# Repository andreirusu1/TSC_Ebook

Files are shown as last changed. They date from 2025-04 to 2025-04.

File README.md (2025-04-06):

# TSC_Ebook
Descriere Proiect
OpenBook este un proiect open source care isi propune sa creeze un e-book reader accesibil si usor de produs. Dispozitivul este conceput pentru a afisa carti digitale, oferind o experienta de lectura similara cu cea a unei carti tiparite, dar cu avantajele tehnologiei moderne. Proiectul meu se bazeaza pe o proiectare simpla si eficienta, iar in aceasta etapa s-au dezvoltat schema electronica, PCB-ul si plasarea componentelor pe placa.

Pentru a transforma aceasta viziune in realitate, am parcurs urmatoarele etape:

1)Engineering Validation (EVT): Am proiectat schema electronica si am creat PCB-ul, asigurandu-ne ca fiecare conexiune este optimizata pentru performanta si fiabilitate.

2)Modelare 3D: Am verificat plasarea componentelor pe placa intr-un mediu 3D, garantand ca designul se integreaza perfect in cadrul final al dispozitivului.

3)Partea de display, baterie si modelele 3D complete ale dispozitivului nu au fost dezvoltate inca. Acest repository se concentreaza pe proiectarea schematica, realizarea PCB-ului si plasarea componentelor pe placa in mediul 3D.

Diagrama Bloc

Mai jos se prezinta o diagrama bloc schematica a principalelor componente si a interconexiunilor acestora:
diagrama

Bill Of Materials (BOM)
Nr.	Componenta	Datasheet URL	Link site pt procurare

1	ESP32-C6-WROOM-1-N8	[Datasheet](https://www.espressif.com/sites/default/files/documentation/esp32-c6-wroom-1_wroom-1u_datasheet_en.pdf)	[link](https://www.digikey.com/en/products/detail/espressif-systems/ESP32-C6-WROOM-1-N8/17728866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)

2	Micro-SD	[Datasheet](https://www.attend.com.tw/data/download/file/112A-TAAR-R03_Spec.pdf)	[link](https://www.digikey.com/en/products/detail/attend-technology/112A-TAAR-R03/17633923)

3	Inductor (68µH)	[Datasheet](https://www.we-online.com/components/products/datasheet/784373170680.pdf)	[link](https://ro.mouser.com/ProductDetail/Wurth-Elektronik/784373170680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)

4	LED	[Datasheet](https://www.bridgelux.com/sites/default/files/resource_media/DS51_Rev%20F%20Bridgelux%20SMD%203030%20Data%20sheet.pdf)	[link](https://www.digikey.com/en/products/detail/bridgelux/BXEM-27E0000-0-000/6618599)

5	Buttons	[Datasheet](https://configured-product-images.s3.amazonaws.com/Datasheets/TL3315.pdf)	[link](https://www.digikey.com/en/products/detail/e-switch/TL3315NF250Q/1870396)

6	Capacitor 	[Datasheet](https://eu.mouser.com/datasheet/2/40/cx5r_KGM-3223198.pdf)	[link](https://ro.mouser.com/ProductDetail/KYOCERA-AVX/0402YD104MAT2A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)

7	Rezistori	[Datasheet](https://www.yageo.com/upload/media/product/products/datasheet/rchip/PYu-RC_Group_51_RoHS_L_12.pdf)	[link](https://www.digikey.com/en/products/detail/yageo/RC0402JR-07100KL/726416)

8	Diode (Schottky Rectifier)	[Datasheet](https://datasheets.kyocera-avx.com/schottky.pdf)	[link](https://www.digikey.com/en/products/detail/kyocera-avx/sd0805s020s1r0/3749517)

9	Connector USB (Type-C)	[Datasheet](https://gct.co/files/drawings/usb4110.pdf)	[Mouser](https://ro.mouser.com/ProductDetail/GCT/USB4110-GF-A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)

10	Test Pad 	[DataSheet](https://cdn-shop.adafruit.com/product-files/3825/3825_diagram.PDF) [link](https://componentsearchengine.com/prices/3825?manufacturer=Adafruit)

 Aceasta lista este orientativa. Componentele si specificatiile pot fi ajustate pe parcursul dezvoltarii.

Functionalitatea Hardware
Proiectul se bazeaza pe microcontroller-ul ESP32-C6, iar designul hardware a fost gandit pentru a optimiza functionalitatea si integrarea componentelor. Principalele aspecte includ:

Alimentare: Dispozitivul este alimentat printr-un regulator de tensiune care transforma 5V in 3.3V, necesar pentru functionarea corecta a ESP32-C6.

Conectivitate: ESP32-C6 pune la dispozitie mai multe interfete de comunicatie (UART, SPI, I2C), esentiale pentru conectarea senzorilor si a altor periferice.

Plasare Componentelor: Schematicul si PCB-ul au fost proiectate pentru a asigura o dispunere eficienta a componentelor, reducand interferentele electromagnetice si facilitand asamblarea manuala sau automatizata.

Verificare 3D: Modelul 3D realizat in Fusion360 (exportat ca .step) a fost folosit pentru a verifica plasarea corecta a componentelor pe placa.

Configurarea Pinilor ESP32-C6
Mai jos sunt detaliate functiile pinilor utilizati in proiect:

Pin	    Functie	          Descriere
GPIO1	  TX	            Transmiterea datelor catre periferice

GPIO3	  RX	            Receptionarea datelor de la periferice

GPIO12	I2C             SDA	Linie de date pentru comunicatia I2C

GPIO13	I2C             SCL	Linie de ceas pentru comunicatia I2C

GPIO14	Buton/Resetare	Functie de resetare a dispozitivului

Configuratia pinilor poate fi ajustata.

Planuri de Dezvoltare: Etapele urmatoare includ integrarea componentelor pentru display, alimentare prin baterie si dezvoltarea completa a modelului 3D al dispozitivului pentru validarea finala.

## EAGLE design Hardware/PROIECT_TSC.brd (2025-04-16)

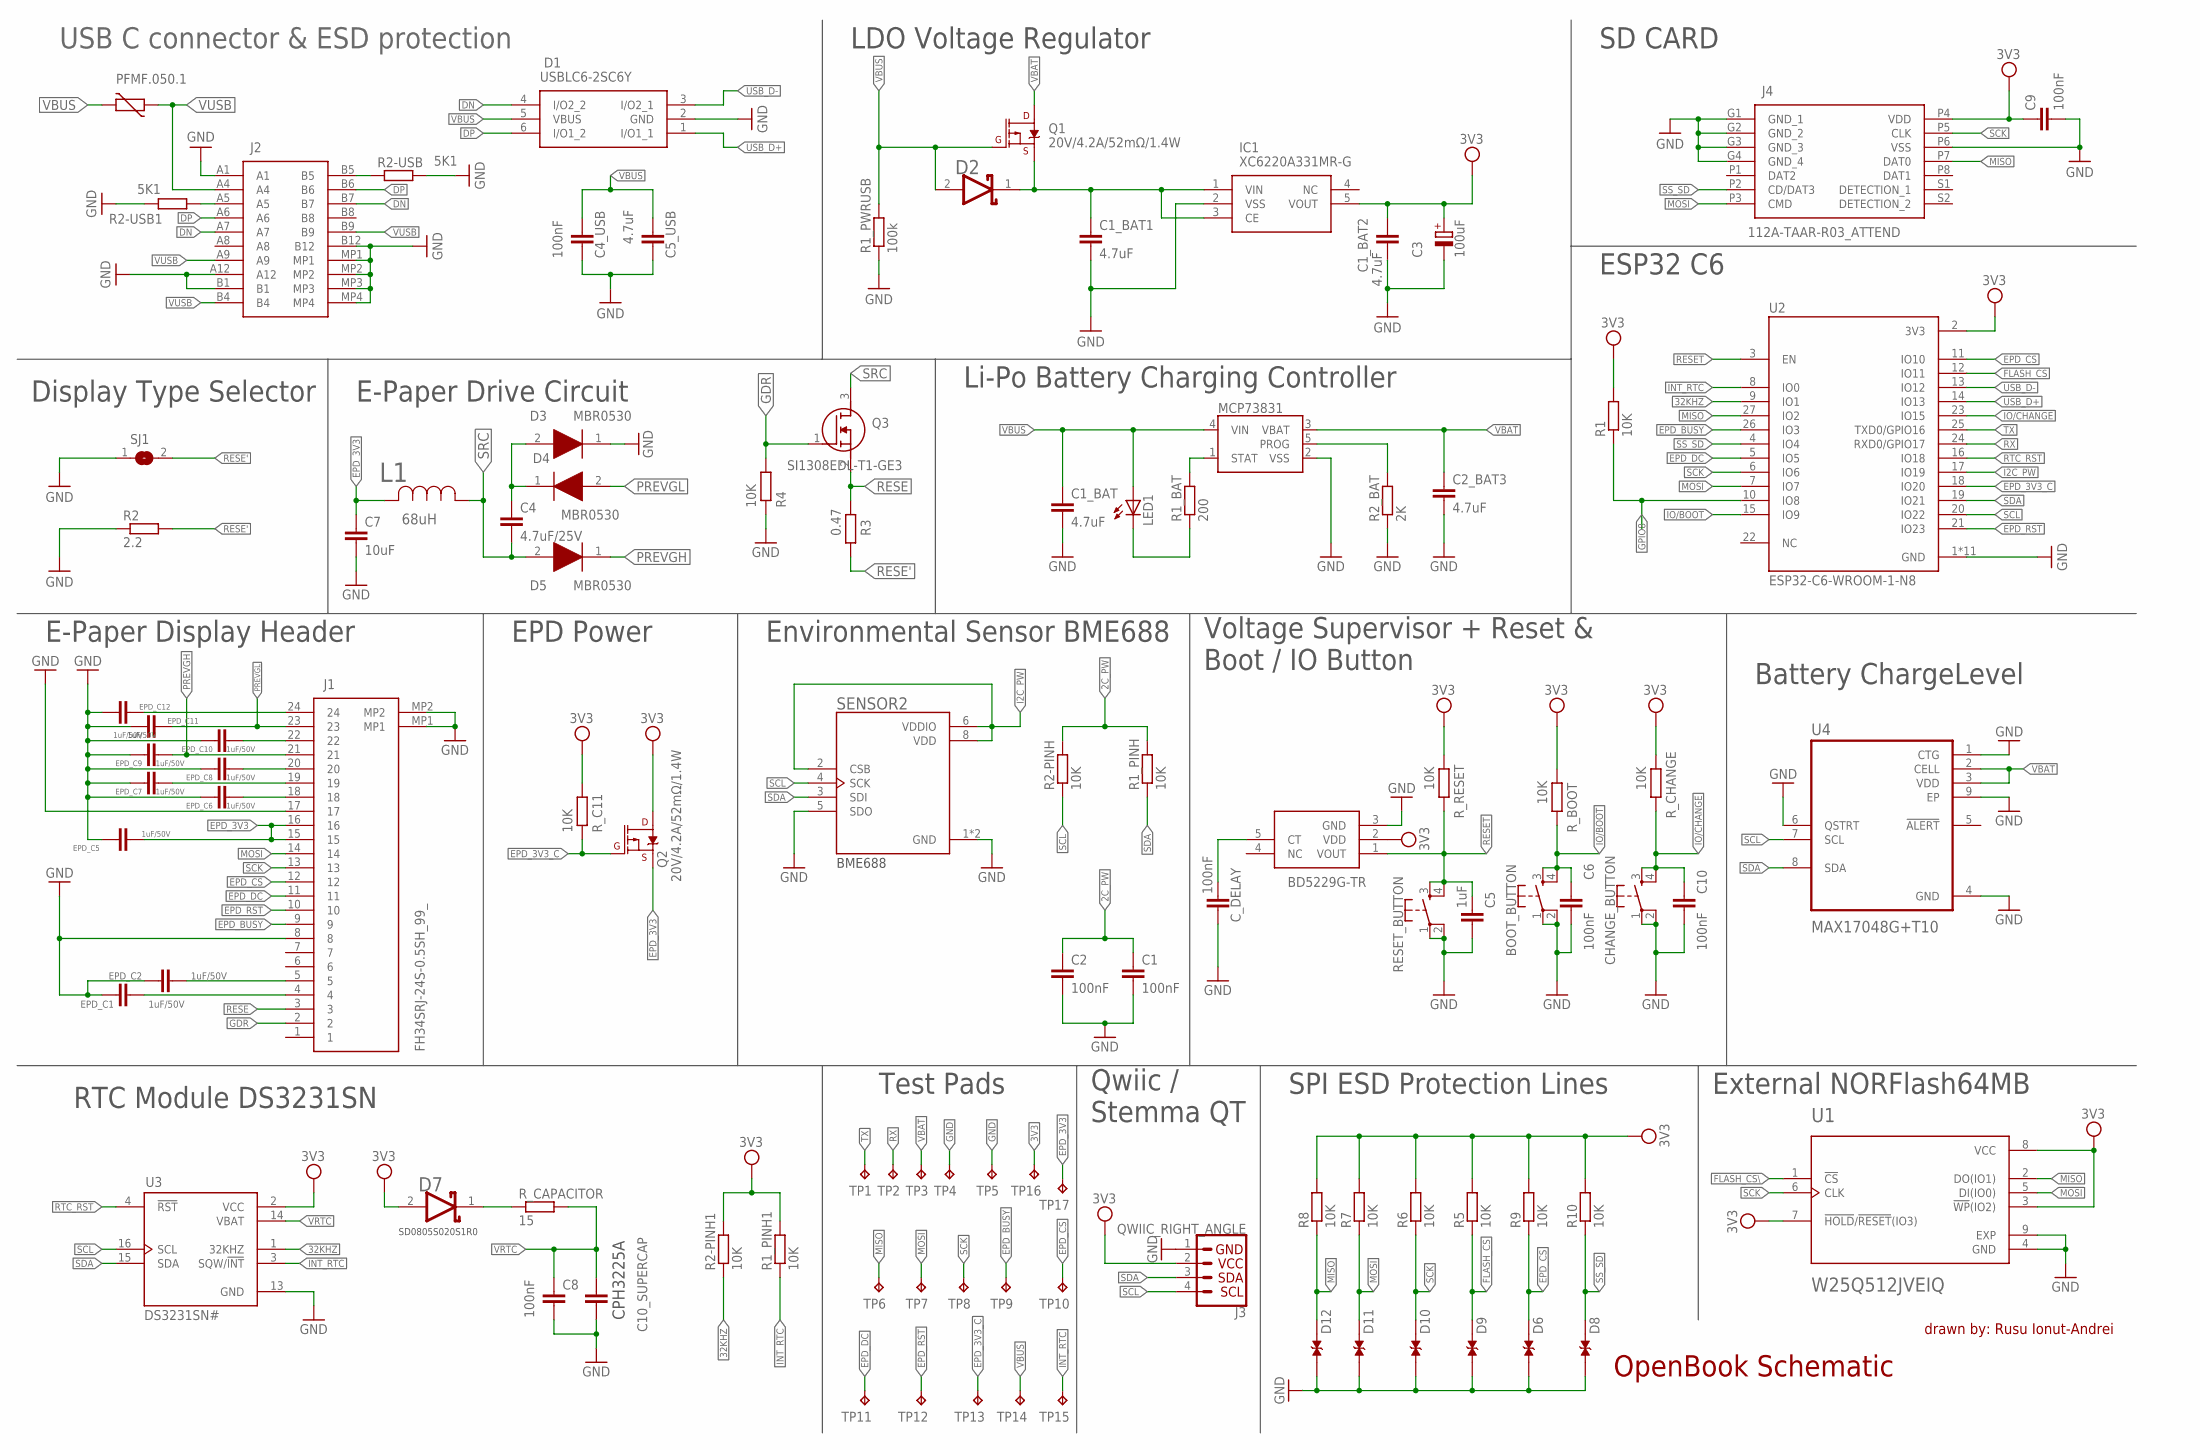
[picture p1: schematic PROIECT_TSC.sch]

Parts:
BOOT_BUTTON: BUTTON_CUSYOMV1; MYBUTTON
C1, C2, C6, C8, C9, C10: 100nF; ESP32_WROVER_EAGLE-LTSPICE_C0402
C1_BAT, C1_BAT1, C2_BAT3: 4.7uF; ESP32_WROVER_EAGLE-LTSPICE_C0402
C1_BAT2, C5_USB: 4.7uF; EAGLE-LTSPICE_C0402
C3: 100uF; RCL_CT3528
C4: 4.7uF/25V; ESP32_WROVER_EAGLE-LTSPICE_C0402
C4_USB: 100nF; EAGLE-LTSPICE_C0402
C5: 1uF; ESP32_WROVER_EAGLE-LTSPICE_C0402
C7: 10uF; EAGLE-LTSPICE_C0402
C10_SUPERCAP: ESP32_WROVER_EAGLE-LTSPICE_CC0402; ESP32_WROVER_EAGLE-LTSPICE_C0402
CHANGE_BUTTON: BUTTON_CUSYOMV1; MYBUTTON
C_DELAY: 100nF; ESP32_WROVER_EAGLE-LTSPICE_C0402
D1: USBLC6-2SC6Y; SOT95P280X145-6N
D2, D7: ESP32_WROVER_AVX---SD0805S020S1R0_AVX_SD0805S020S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; ESP32_WROVER_AVX---SD0805S020S1R0_AVX_SD0805S020S1R0_0
D3, D4, D5: MBR0530; SOD3716X135N
D6, D8, D9, D10, D11, D12: PGB1010603MR; DIOC1608X36N
EPD_C1, EPD_C2, EPD_C5, EPD_C6, EPD_C7, EPD_C8, EPD_C9, EPD_C10, EPD_C11, EPD_C12: 1uF/50V; ESP32_WROVER_EAGLE-LTSPICE_C0402
IC1: XC6220A331MR-G; SOT95P280X120-5N
IC2: BD5229G-TR; SOT95P280X125-5N
J1: FH34SRJ-24S-0.5SH_99_; FH34SRJ24S05SH99
J2: SAMACSYS_PARTS_USB4110-GF-A; SAMACSYS_PARTS_USB4110GFA
J3: QWIIC_RIGHT_ANGLE; JST04_1MM_RA
J4: 112A-TAAR-R03_ATTEND; 112ATAARR03ATTEND
L1: 68uH; IND_4828-WE-TPC_WRE
LED1: ADAFRUIT_LEDCHIP-LED0603; ADAFRUIT_CHIP-LED0603
MCP73831: ESP32_WROVER_SPARKFUN-IC-POWER_MCP73831; ESP32_WROVER_SPARKFUN-IC-POWER_SOT23-5
PFMF.050.1: ESP32C6_VARISTORCN1812; ESP32C6_VARISTOR_CT/CN1812
Q1, Q2: 20V/4.2A/52mΩ/1.4W; ESP32_WROVER_SPARKFUN-DISCRETESEMI_SOT23-3
Q3: SI1308EDL-T1-GE3; SOT65P210X110-3N
R1, R1_PINH, R1_PINH1, R2-PINH, R2-PINH1, R4, R5, R6, R7, R8, R9, R10: 10K; ESP32_WROVER_EAGLE-LTSPICE_R0402
R1_BAT: 200; ESP32_WROVER_EAGLE-LTSPICE_R0402
R1_PWRUSB: 100k; ESP32_WROVER_EAGLE-LTSPICE_R0402
R2: 2.2; ESP32_WROVER_EAGLE-LTSPICE_R0402
R2-USB, R2-USB1: 5K1; ESP32_WROVER_EAGLE-LTSPICE_R0402
R2_BAT: 2K; ESP32_WROVER_EAGLE-LTSPICE_R0402
R3: 0.47; ESP32_WROVER_EAGLE-LTSPICE_R0402
RESET_BUTTON: BUTTON_CUSYOMV1; MYBUTTON
R_BOOT: 10K; ESP32_WROVER_EAGLE-LTSPICE_R0402
R_C11: 10K; ESP32_WROVER_EAGLE-LTSPICE_R0402
R_CAPACITOR: 15; ESP32_WROVER_EAGLE-LTSPICE_R0402
R_CHANGE: 10K; ESP32_WROVER_EAGLE-LTSPICE_R0402
R_RESET: 10K; ESP32_WROVER_EAGLE-LTSPICE_R0402
SENSOR2: ESP32_WROVER_BME680_BME680; ESP32_WROVER_BME680_PSON80P300X300X100-8N
SJ1: SJ
TP1, TP2, TP3, TP4, TP5, TP6, TP7, TP8, TP9, TP10, TP11, TP12, TP13, TP14, TP15, TP16, TP17: TPTP20R; TP20R
U1: W25Q512JVEIQ; SON127P600X800X80-9N
U2: ESP32-C6-WROOM-1-N8; XCVR_ESP32-C6-WROOM-1-N8
U3: DS3231SN#; SOIC127P1032X265-16N
U4: MAX17048G+T10; SON50P200X200X80-9N

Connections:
2C_PW: C1.1, C2.1, R1_PINH.2, R2-PINH.2
3V3: C1_BAT2.1, C3.+, C9.1, D7.2 (ANODE), IC1.5 (VOUT), IC2.2 (VDD), J3.2, J4.P4 (VDD), Q2.3 (D), R1.2, R1_PINH1.2, R2-PINH1.2, R5.2, R6.2, R7.2, R8.2, R9.2, R10.2, R_BOOT.2, R_C11.2, R_CHANGE.2, R_RESET.2, TP16.TP, U1.3 (!WP!(IO2)), U1.7 (!HOLD!/!RESET!(IO3)), U1.8 (VCC), U2.2 (3V3), U3.2 (VCC)
32KHZ: R2-PINH1.1, U2.9 (IO1), U3.1 (32KHZ)
DN: D1.4 (I/O2_2), J2.A7, J2.B7
DP: D1.6 (I/O1_2), J2.A6, J2.B6
EPD_3V3: C7.1, EPD_C5.2, J1.15, J1.16, L1.2, Q2.2 (S), TP17.TP
EPD_3V3_C: Q2.1 (G), R_C11.1, TP13.TP, U2.18 (IO20)
EPD_BUSY: J1.9, TP9.TP, U2.26 (IO3)
EPD_CS: D6.2, J1.12, R9.1, TP10.TP, U2.11 (IO10)
EPD_DC: J1.11, TP11.TP, U2.5 (IO5)
EPD_RST: J1.10, TP12.TP, U2.21 (IO23)
FLASH_CS: D9.2, R5.1, U2.12 (IO11)
FLASH_CS\: U1.1 (!CS)
GDR: J1.2, Q3.1 (G), R4.2
GND: BOOT_BUTTON.1, BOOT_BUTTON.2, C1.2, C1_BAT.2, C1_BAT1.2, C1_BAT2.2, C2.2, C2_BAT3.2, C3.-, C4_USB.2, C5.2, C5_USB.2, C6.2, C7.2, C8.2, C9.2, C10.2, C10_SUPERCAP.2, CHANGE_BUTTON.1, CHANGE_BUTTON.2, C_DELAY.2, D1.2 (GND), D3.1 (K), D6.1, D8.1, D9.1, D10.1, D11.1, D12.1, EPD_C1.1, EPD_C2.1, EPD_C5.1, EPD_C6.1, EPD_C7.1, EPD_C8.1, EPD_C9.1, EPD_C10.1, EPD_C11.1, EPD_C12.1, IC1.2 (VSS), IC2.3 (GND), J1.8, J1.17, J1.MP1, J1.MP2, J2.A1, J2.A12, J2.B1, J2.B12, J2.MP1, J2.MP2, J2.MP3, J2.MP4, J3.1, J4.G1 (GND_1), J4.G2 (GND_2), J4.G3 (GND_3), J4.G4 (GND_4), J4.P6 (VSS), MCP73831.2 (VSS), R1_PWRUSB.1, R2.1, R2-USB.2, R2-USB1.1, R2_BAT.1, R4.1, RESET_BUTTON.1, RESET_BUTTON.2, SENSOR2.1 (GND), SENSOR2.5 (SDO), SENSOR2.7 (GND), SJ1.1, TP4.TP, TP5.TP, U1.4 (GND), U1.9 (EXP), U2.1 (GND), U2.28 (GND), U2.29_1 (GND), U2.29_2 (GND), U2.29_3 (GND), U2.29_4 (GND), U2.29_5 (GND), U2.29_6 (GND), U2.29_7 (GND), U2.29_8 (GND), U2.29_9 (GND), U3.13 (GND), U4.1 (CTG), U4.4 (GND), U4.6 (QSTRT), U4.9 (EP)
GPIO8: R1.1, U2.10 (IO8)
I2C_PW: SENSOR2.2 (CSB), SENSOR2.6 (VDDIO), SENSOR2.8 (VDD), U2.17 (IO19)
INT_RTC: R1_PINH1.1, TP15.TP, U2.8 (IO0), U3.3 (SQW/!INT)
IO/BOOT: BOOT_BUTTON.3, BOOT_BUTTON.4, C6.1, R_BOOT.1, U2.15 (IO9)
IO/CHANGE: C10.1, CHANGE_BUTTON.3, CHANGE_BUTTON.4, R_CHANGE.1, U2.23 (IO15)
MISO: D12.2, J4.P7 (DAT0), R8.1, TP6.TP, U1.2 (DO(IO1)), U2.27 (IO2)
MOSI: D11.2, J1.14, J4.P3 (CMD), R7.1, TP7.TP, U1.5 (DI(IO0)), U2.7 (IO7)
unnamed: C1_BAT1.1, D2.1 (CATHODE), IC1.1 (VIN), IC1.3 (CE), Q1.2 (S)
unnamed: J2.A5, R2-USB1.2
unnamed: C4.1, D3.2 (A), D4.1 (K)
unnamed: J2.B5, R2-USB.1
unnamed: MCP73831.1 (STAT), R1_BAT.2
unnamed: MCP73831.5 (PROG), R2_BAT.2
unnamed: LED1.C, R1_BAT.1
unnamed: EPD_C12.2, J1.24
unnamed: EPD_C2.2, J1.5
unnamed: EPD_C1.2, J1.4
unnamed: EPD_C6.2, J1.18
unnamed: EPD_C10.2, J1.22
unnamed: EPD_C8.2, J1.20
unnamed: D7.1 (CATHODE), R_CAPACITOR.1
unnamed: EPD_C7.2, J1.19
unnamed: C_DELAY.1, IC2.5 (CT)
PREVGH: D5.1 (K), EPD_C9.2, J1.21
PREVGL: D4.2 (A), EPD_C11.2, J1.23
RESE: J1.3, Q3.2 (S), R3.2
RESE': R2.2, R3.1, SJ1.2
RESET: C5.1, IC2.1 (VOUT), RESET_BUTTON.3, RESET_BUTTON.4, R_RESET.1, U2.3 (EN)
RTC_RST: U2.16 (IO18), U3.4 (!RST)
RX: TP2.TP, U2.24 (RXD0/GPIO17)
SCK: D10.2, J1.13, J4.P5 (CLK), R6.1, TP8.TP, U1.6 (CLK), U2.6 (IO6)
SCL: J3.4, R2-PINH.1, SENSOR2.4 (SCK), U2.20 (IO22), U3.16 (SCL), U4.7 (SCL)
SDA: J3.3, R1_PINH.1, SENSOR2.3 (SDI), U2.19 (IO21), U3.15 (SDA), U4.8 (SDA)
SRC: C4.2, D5.2 (A), L1.1, Q3.3 (D)
SS_SD: D8.2, J4.P2 (CD/DAT3), R10.1, U2.4 (IO4)
TX: TP1.TP, U2.25 (TXD0/GPIO16)
USB_D+: D1.1 (I/O1_1), U2.14 (IO13)
USB_D-: D1.3 (I/O2_1), U2.13 (IO12)
VBAT: C2_BAT3.1, MCP73831.3 (VBAT), Q1.3 (D), TP3.TP, U4.2 (CELL), U4.3 (VDD)
VBUS: C1_BAT.1, C4_USB.1, C5_USB.1, D1.5 (VBUS), D2.2 (ANODE), LED1.A, MCP73831.4 (VIN), PFMF.050.1.2, Q1.1 (G), R1_PWRUSB.2, TP14.TP
VRTC: C8.1, C10_SUPERCAP.1, R_CAPACITOR.2, U3.14 (VBAT)
VUSB: J2.A4, J2.A9, J2.B4, J2.B9, PFMF.050.1.1

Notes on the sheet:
USB C connector & ESD protection
LDO Voltage Regulator
SD CARD
Display Type Selector
E-Paper Drive Circuit
ESP32 C6
Li-Po Battery Charging Controller
E-Paper Display Header
EPD Power
Environmental Sensor BME688
BME688
Battery ChargeLevel
Voltage Supervisor + Reset & Boot / IO Button
OpenBook Schematic
drawn by: Rusu Ionut-Andrei
External NORFlash64MB
SPI ESD Protection Lines
Qwiic / Stemma QT
Test Pads
RTC Module DS3231SN
CPH3225A
SD0805S020S1R0

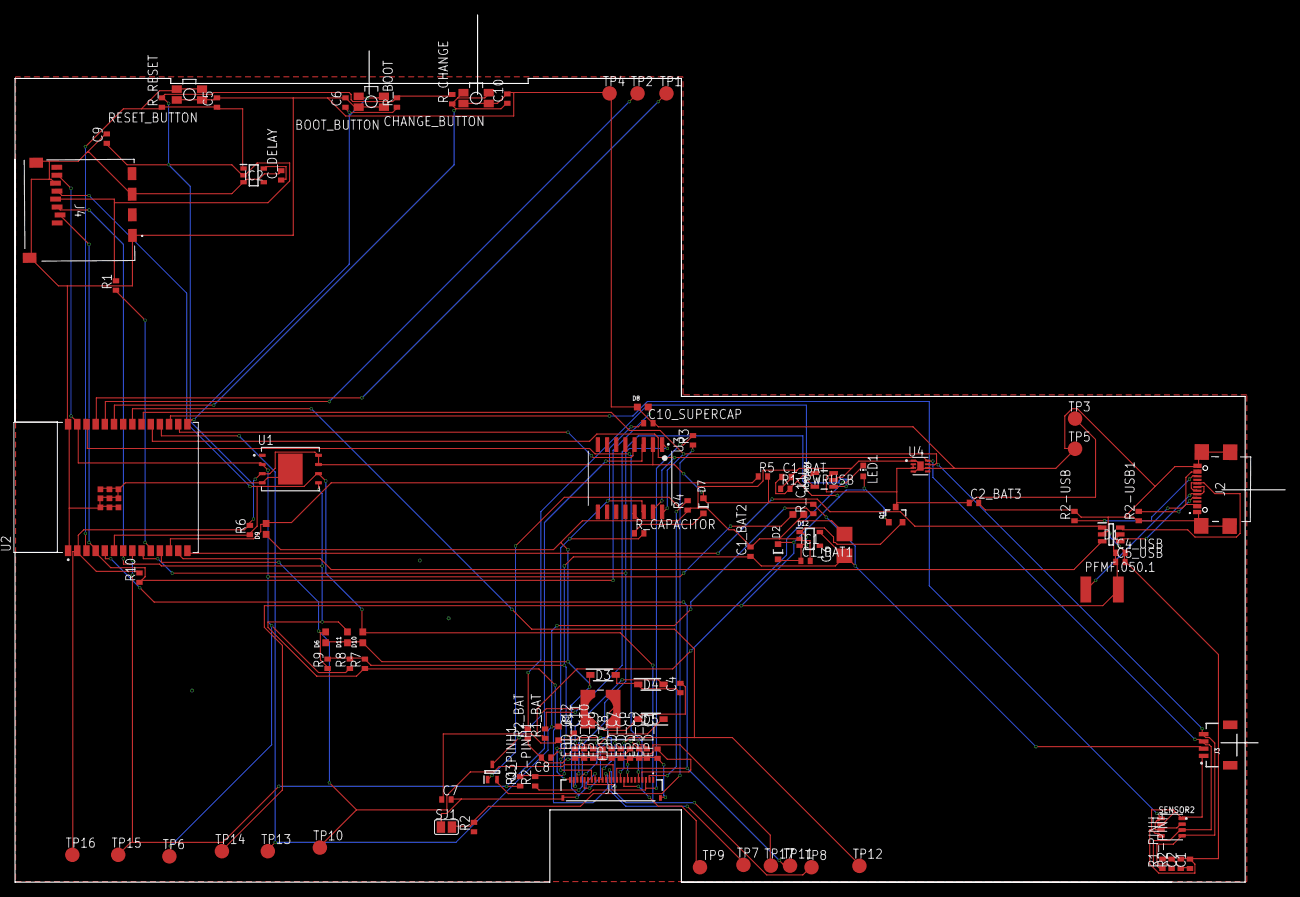
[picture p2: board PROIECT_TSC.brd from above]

Board: 2 copper layers, 175.7 x 120.0 mm, 103 parts (0 on the bottom side), 56 nets.

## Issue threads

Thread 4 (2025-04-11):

Error in PCB

Borromeu, 2025-04-11:
After checking the design rules for pcb, I found this error.

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

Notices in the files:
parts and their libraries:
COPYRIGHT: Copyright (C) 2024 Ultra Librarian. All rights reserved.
